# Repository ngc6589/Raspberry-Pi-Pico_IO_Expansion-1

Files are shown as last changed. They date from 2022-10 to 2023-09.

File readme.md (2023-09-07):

# Raspberry Pi Pico I/O Expansion Board

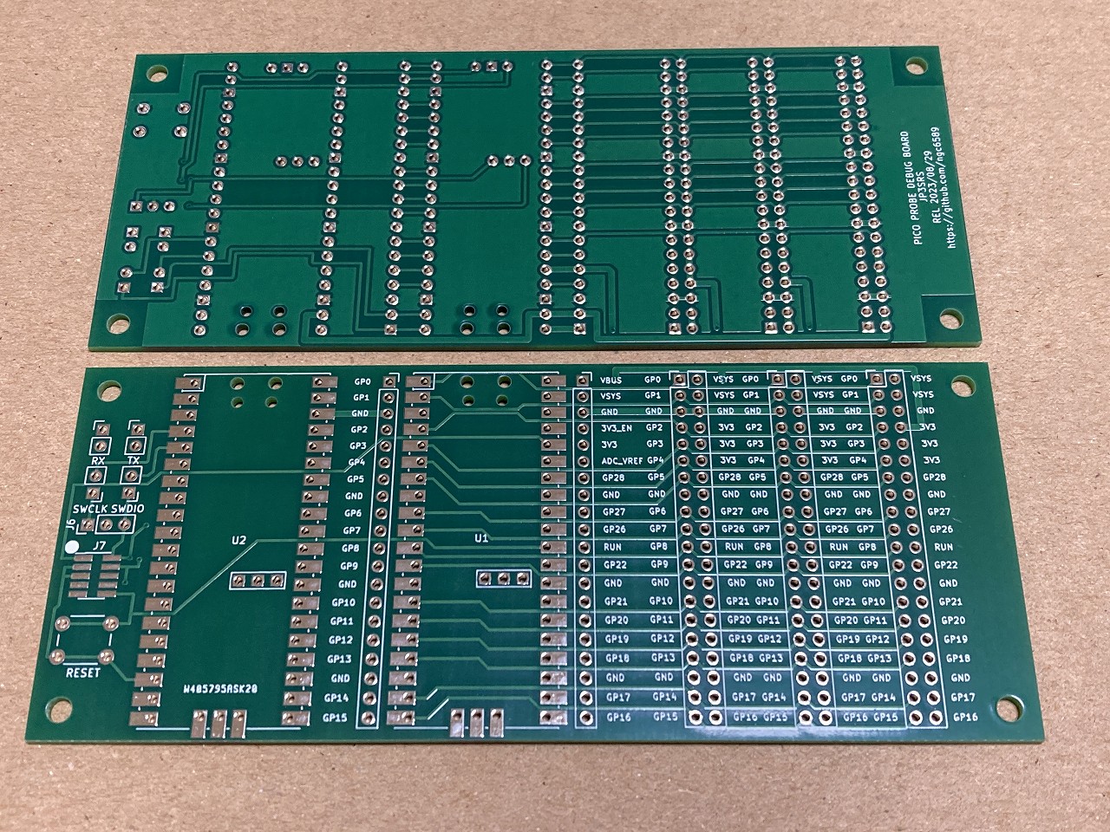
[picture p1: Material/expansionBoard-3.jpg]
expansionBoard


# この基板について

これは、Raspberry Pi Pico のピンを 2x20 のヘッダーピン（ピンソケット）に出す基板になります。ただし 2x20 ヘッダーピンは一部のピンを電源ピンに置き換えをしています。  
VBUS ピンは VSYS  
3V3_EN ピンは 3V3  
ADC_VREF は 3V3  

|Name|Pin|Pin|Name|
|---|---|---|---|
|GPIO0|1|40|VBUS → VSYS|
|GPIO1|2|39|VSYS|
|GND|3|38|GND|
|GPIO2|4|37|3V3_EN → 3V3|
|GPIO3|5|36|3V3|
|GPIO4|6|35|ADC_VREF → 3V3|
|GPIO5|7|34|GPIO28|
|GND|8|33|AGND|
|GPIO6|9|32|GPIO27|
|GPIO7|10|31|GPIO26|
|GPIO8|11|30|RUN|
|GPIO9|12|29|GPIO22|
|GND|13|28|GND|
|GPIO10|14|27|GPIO21|
|GPIO11|15|26|GPIO20|
|GPIO12|16|25|GPIO19|
|GPIO13|17|24|GPIO18|
|GND|18|23|GND|
|GPIO14|19|22|GPIO17|
|GPIO15|20|21|GPIO16|

# 回路図・ガーバーファイル
回路図は Schematic.pdf を参照してください。  
ガーバーファイルは KiCad フォルダーの Gerber-20230829 フォルダーを参照してください。

# Pico Probe 接続
基板端の U2 は Pico Probe の Raspberry Pi Pico が実装される場所です。gdb でデバッグをする時は実装してください。  
Pico Probe は使用しないけど、刺したまま使用するときは基板の JP1 ～ JP4 のジャンパーピンを抜くことで分離できます。

# 電源
Pico Probe 用 Raspberry Pi Pico とターゲット(動作用)の Raspberry Pi Pico の VSYS 端子は接続されています。なので USB ケーブルをどちらに挿しても（同時挿し含む）Raspberry Pi Pico 並びに、2x20 ヘッダピン・ヘッダソケットの VSYS ピンには電源が供給されます。  
VSYS は USB コネクタの VBUS からショットキーバリアダイオード通過後の端子になるため 5V よりかは若干低い電圧であることは理解下さい。  
  
3V3 はターゲット Raspberry Pi Pico の 3V3 端子から供給されます。Raspberry Pi Pico の基板に 3.3V DC/DC コンバーターが搭載されていますが、Raspberry Pi Pico Datasheet の記載には、3V3 のピンは 300mA 以下推奨とあります。

# 組み立て例
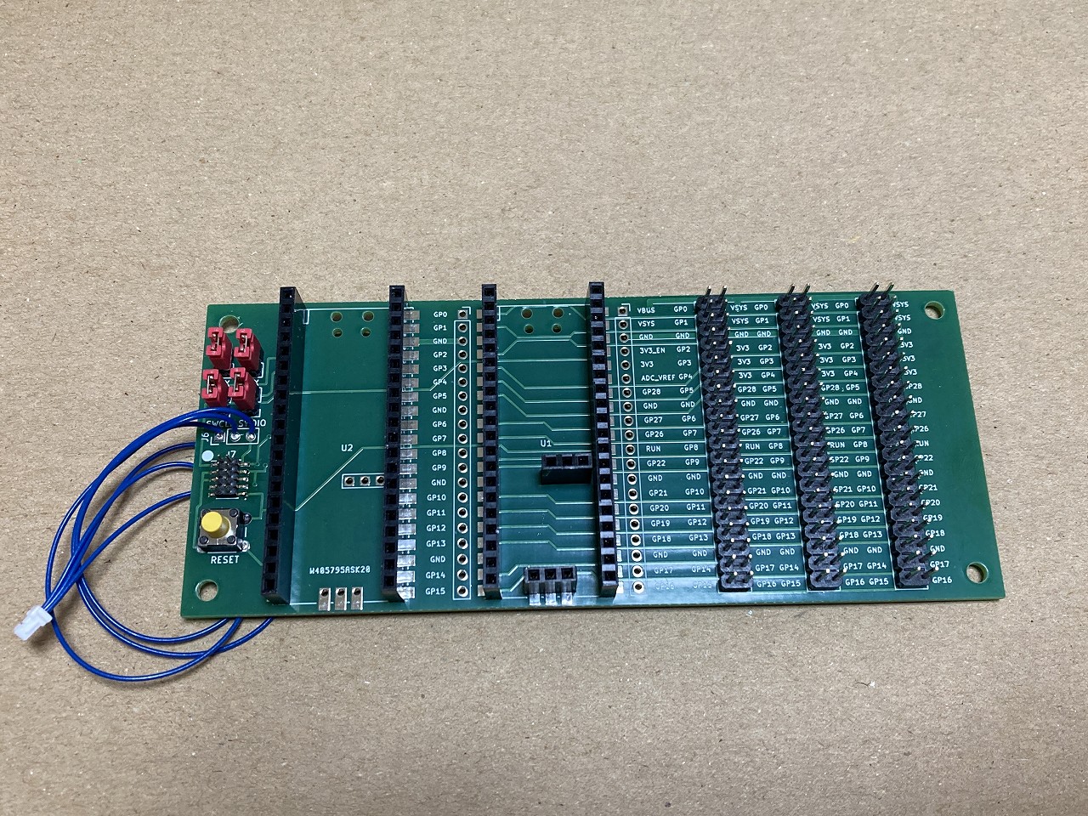
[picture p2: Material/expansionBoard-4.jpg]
expansionBoard


組み立て例は、Raspberry Pi Pico ボードをピンソケットで、横の I/O をピンヘッダーで出しました。
2x5 1.27mm ピッチヘッダピンは表面実装で、J-Link SWD 接続などで使うハーフピッチのコネクタ端子です。PicoProbe だけで使うときは実装不要です。

# 部品例

上記組み立て例の部品表は以下のようになります。

|部品番号|部品名|数量|通販アドレス|備考|
|---|---|---|---|---|
|U1, U2|ピンソケット (メス) 1×20 (20P)|4|https://akizukidenshi.com/catalog/g/gC-03077/||
|JP1～JP4|ピンヘッダ 1×2 (2P) (10個入)|1|https://akizukidenshi.com/catalog/g/gC-08593/||
|U1|ピンソケット(メス) 1×3(3P)|2|https://akizukidenshi.com/catalog/g/gC-10098/||
|J1, J2, J3|ピンヘッダ 2×20 (40P)|3|https://akizukidenshi.com/catalog/g/gC-00080/|
|JP1～JP4|ジャンパーピン赤(2.54mmピッチ) (25個入)|1|https://akizukidenshi.com/catalog/g/gP-03688/|
|SW1|タクトスイッチ（黄色）|1|https://akizukidenshi.com/catalog/g/gP-03650/|
|J6|コネクタ付コード 3P (青×3) 1mmピッチ|1|https://akizukidenshi.com/catalog/g/gC-11507/|
|J7|ピンヘッダ 2×5(10P) 表面実装用 1.27mmピッチ|1|https://akizukidenshi.com/catalog/g/gC-10904/|
|J4, J5|未実装||||

# 引用
Raspberry Pi PICO の KiCad ライブラリは https://github.com/ncarandini/KiCad-RP-Pico を利用しています。

# 使用例

## Raspberry Pi Pico
Raspberry Pi PIco は3ピンデバッグ端子にヘッダピンを付けて装着して下さい。
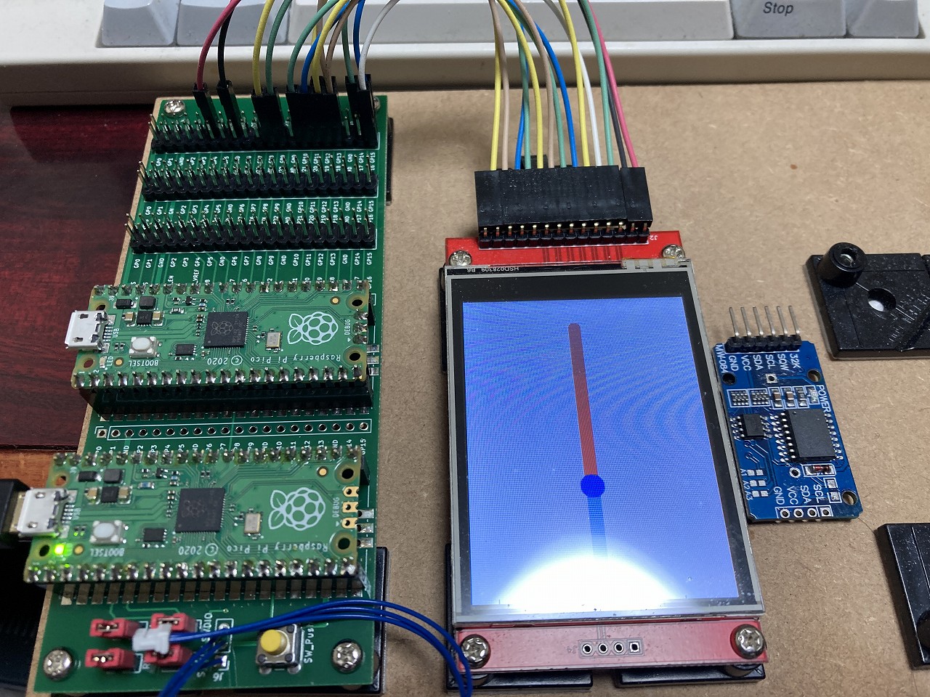
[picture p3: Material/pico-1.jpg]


## Raspberry Pi Pico H
ヘッダピンがあらかじめ実装されている Raspberry Pi Pico H はデバッグ端子は1mm間隔のJST SHコネクタになっています。基板からSHコネクタの線を出して接続します

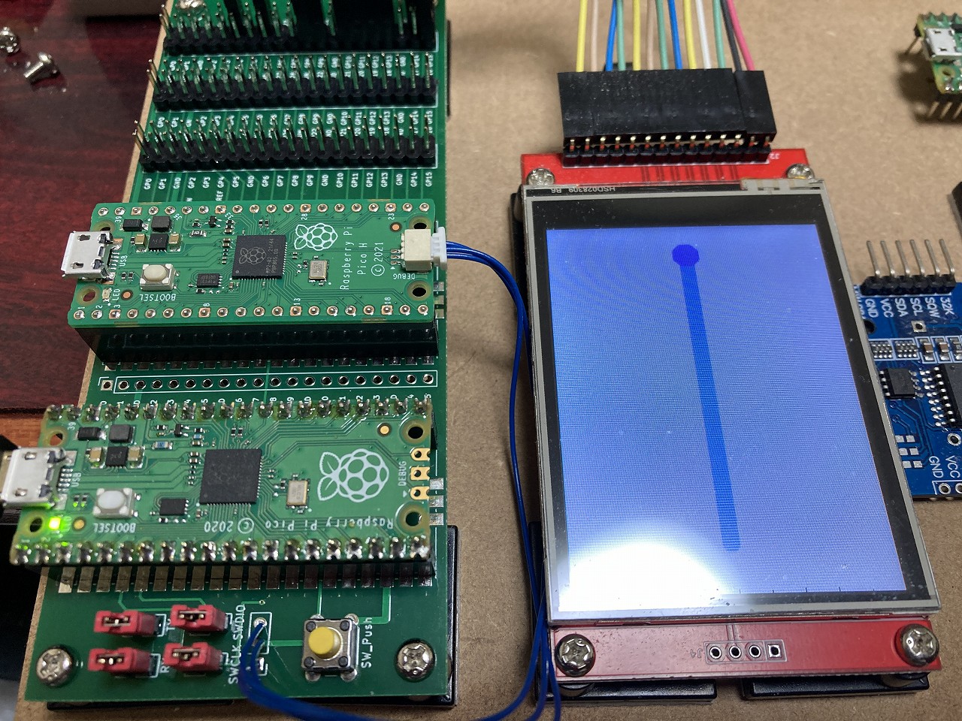
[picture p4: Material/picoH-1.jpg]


## Raspberry Pi Pico W
Raspberry Pi PIco 無線LAN付きは3ピンデバッグ端子にヘッダピンを付けて装着して下さい。

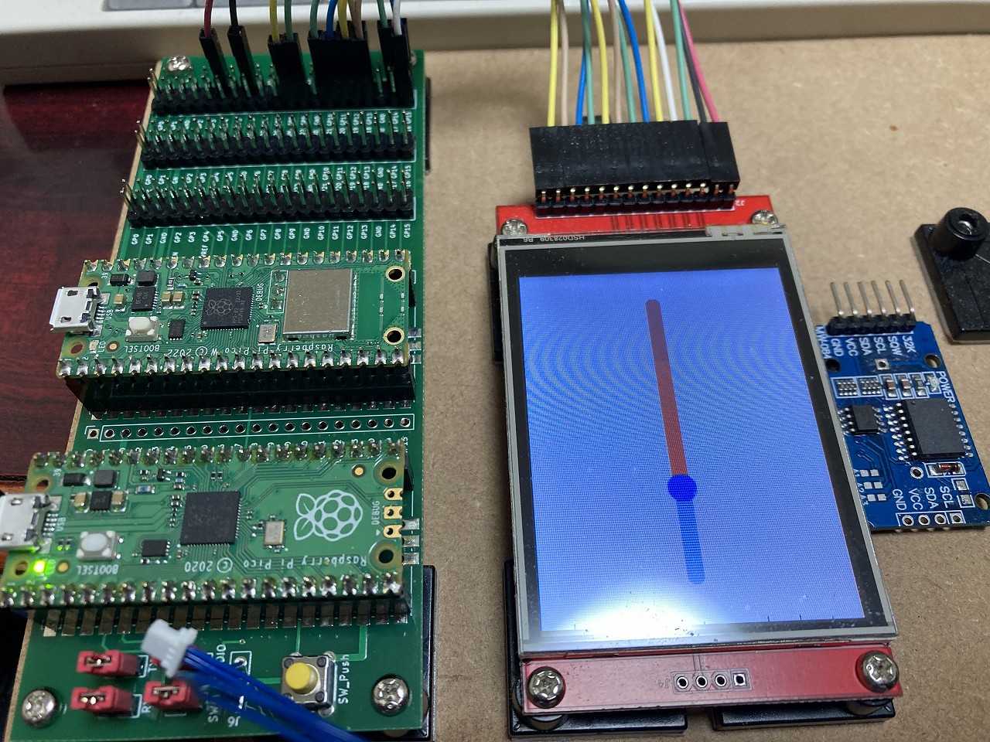
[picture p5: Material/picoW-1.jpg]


## Raspberry Pi Pico WH
ヘッダピン付き Raspberry Pi Pico HW は入手出来ていませんので写真はありませんが、Pico H 同様 JST SH コネクタでデバッグ端子に接続して下さい。

## SWD 接続のデバッガで使用する

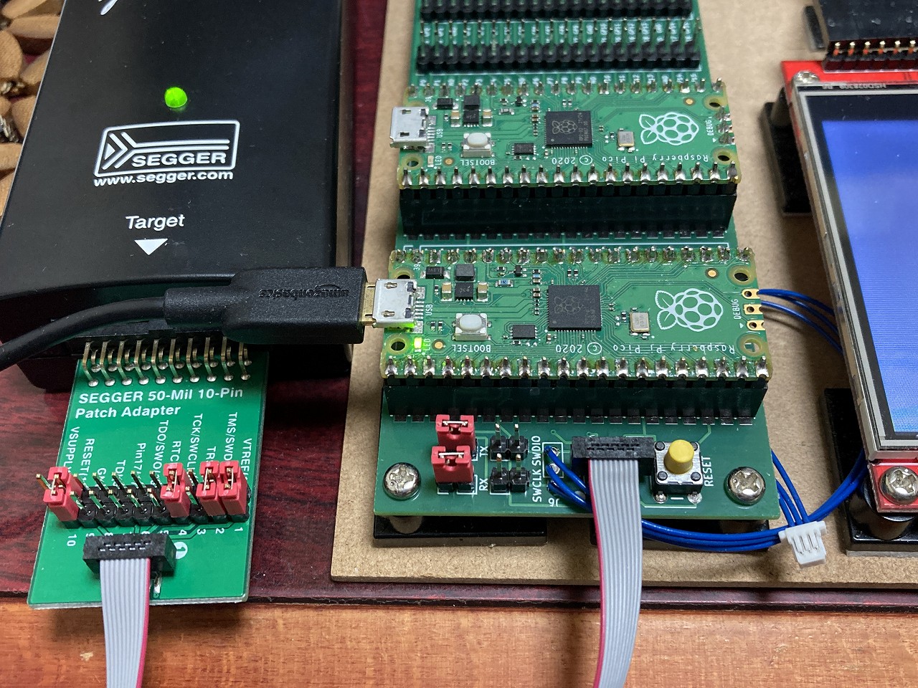
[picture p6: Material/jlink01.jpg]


2x5 ヘッダピンに SWD 接続可能なデバッガのケーブルを取り付けることで、違うデバッガを使用することができます。

**基板の SWD/SWCLK のジャンパは抜いてください。PicoProbe とショートしますので故障の原因となります。**

この接続でも PicoProbe は USB シリアルとして使用可能ですので、Raspberry Pi Pico の puts 出力などは PicoProbe 経由で受けられます。

# 頒布

https://www.em9system.com/?p=1047

にて在庫限りでピンソケット、ピンヘッダなど部品付きセットを頒布しています。

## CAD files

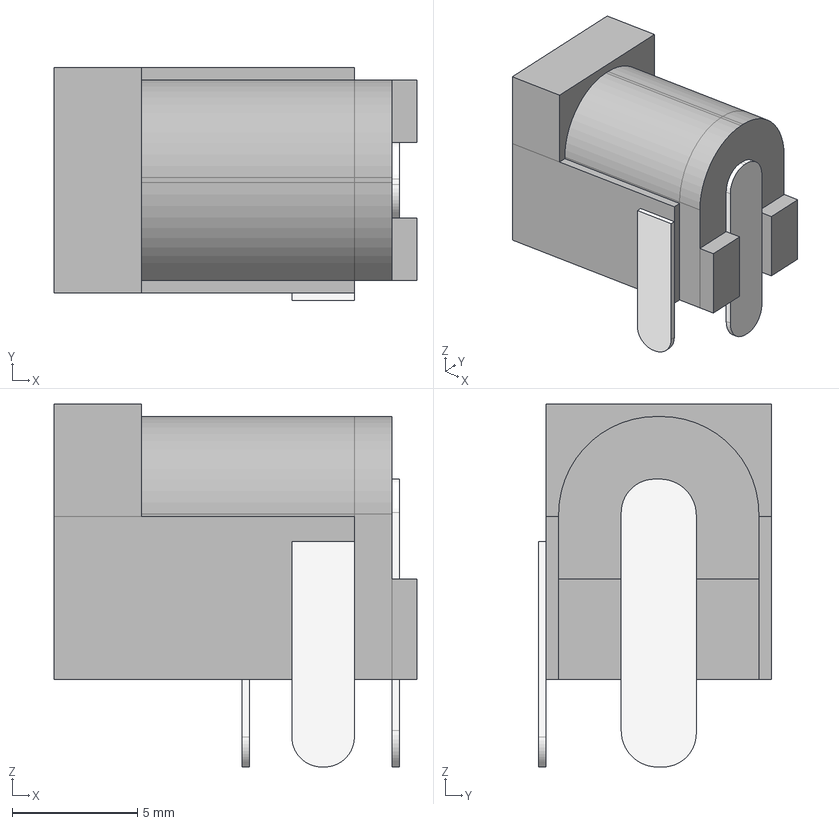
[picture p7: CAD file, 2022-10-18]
KiCad/_LocalLibraries/MJ-179PH-Part.step
14.5 x 9.30 x 14.5 mm

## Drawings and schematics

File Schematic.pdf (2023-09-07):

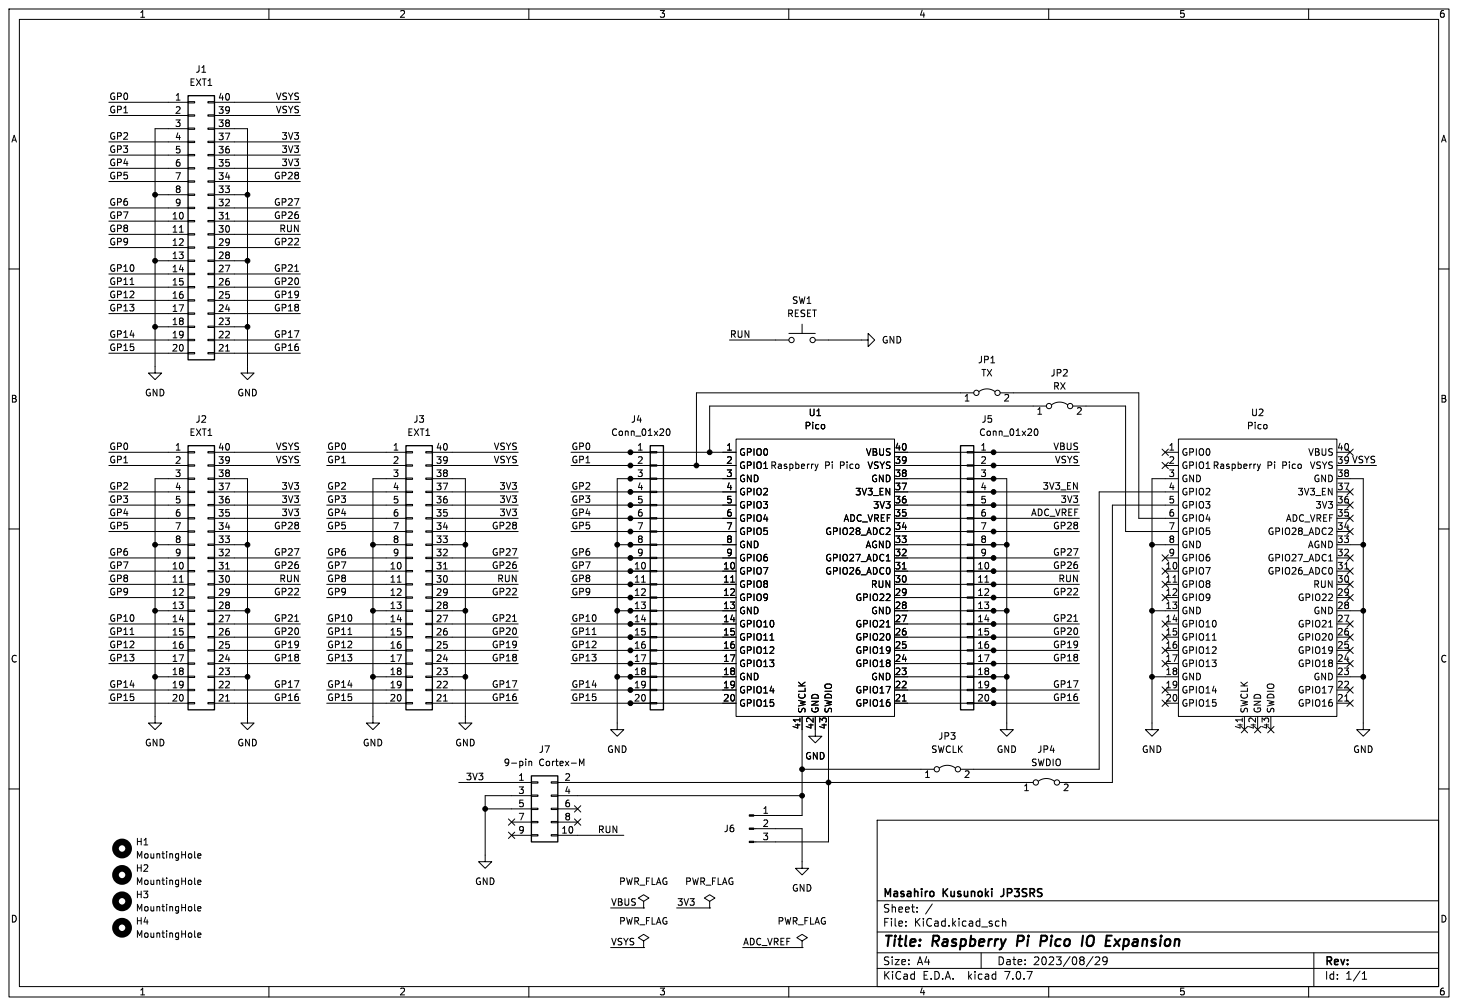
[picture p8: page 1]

Id: 1/1 Title: Raspberry Pi Pico IO Expansion

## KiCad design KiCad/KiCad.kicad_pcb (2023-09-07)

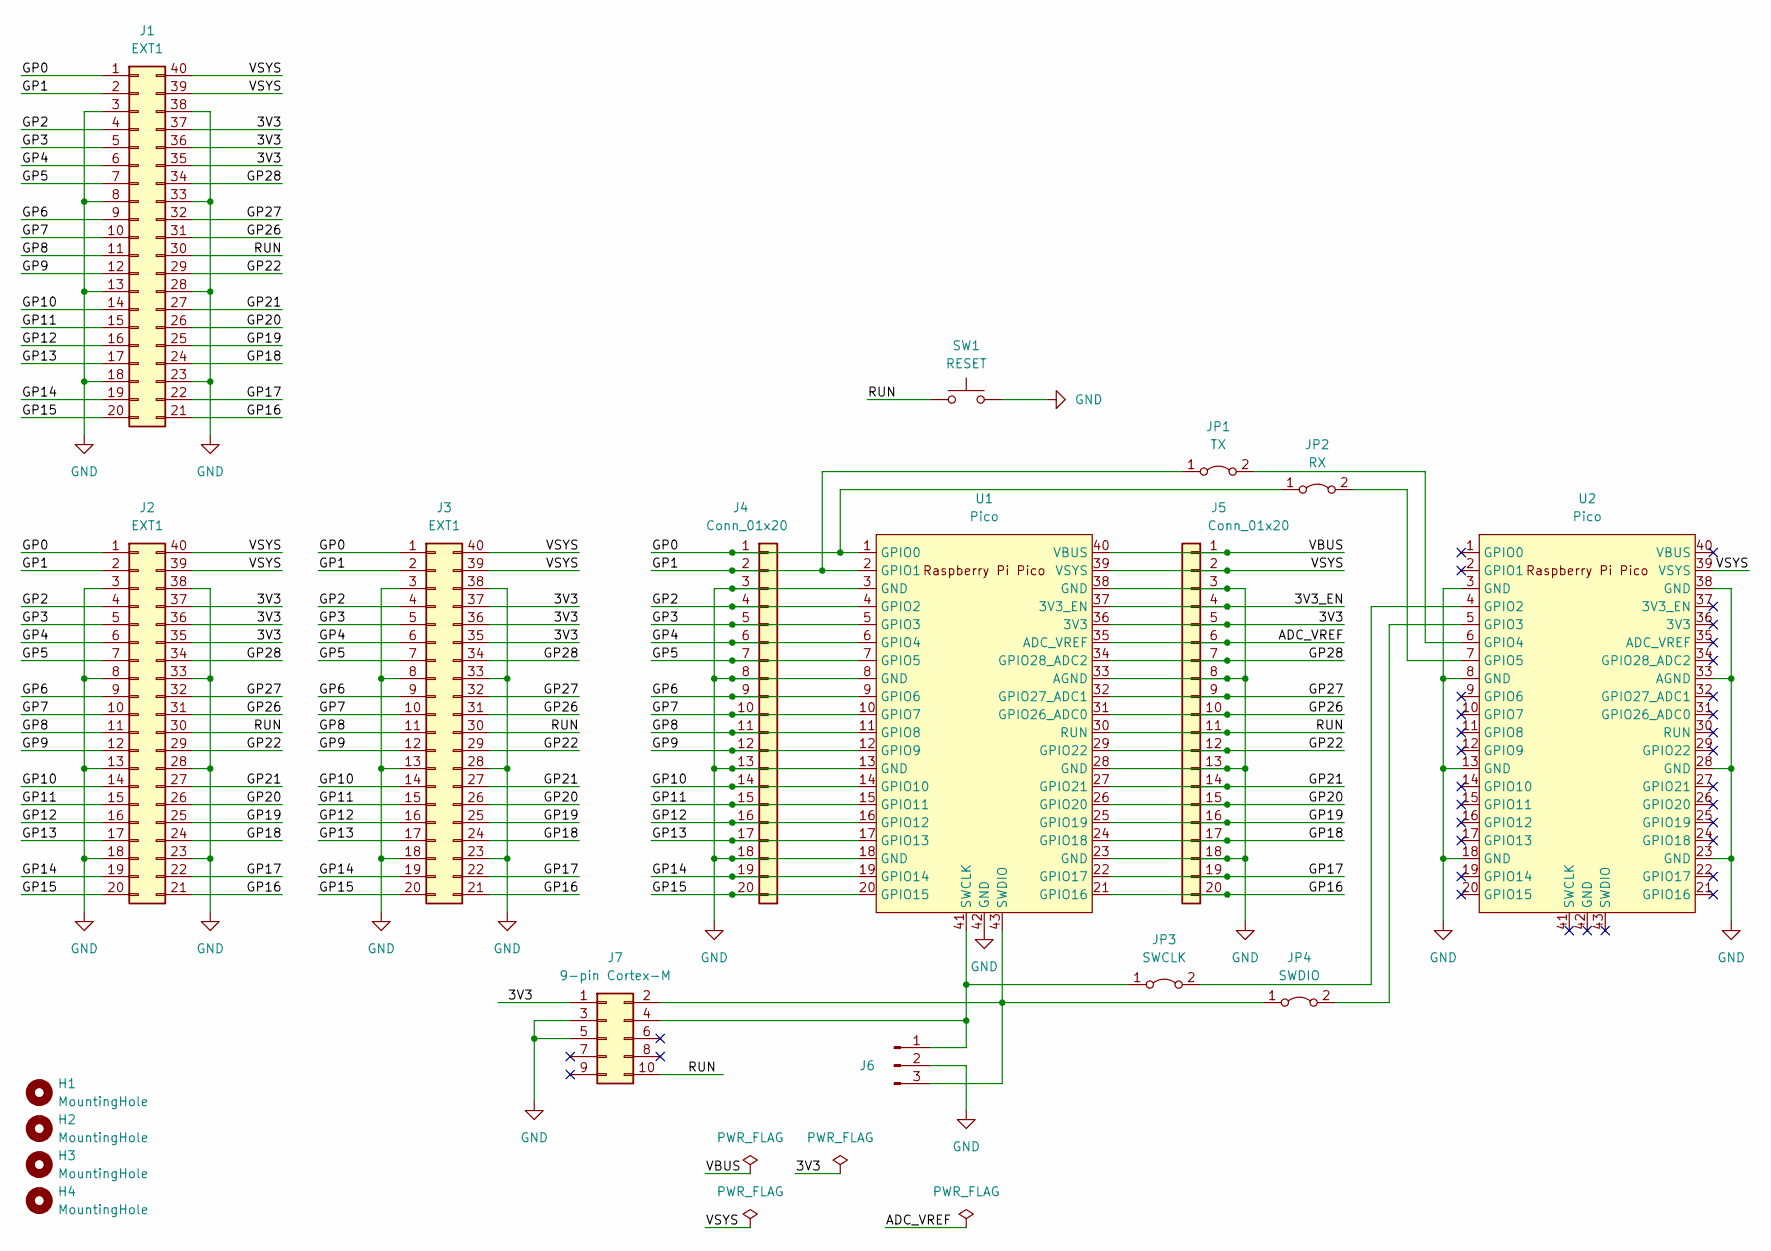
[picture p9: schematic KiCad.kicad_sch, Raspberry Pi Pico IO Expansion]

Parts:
H1, H2, H3, H4: MountingHole; MountingHole_3.2mm_M3
J1, J2, J3: EXT1; dualHeader
J4: Conn_01x20; leftHeader
J5: Conn_01x20; rightHeader
J6: Conn_01x03_Pin; PinHeader_1x03_P2.54mm_Vertical
J7: 9-pin Cortex-M; PinHeader_2x05_P1.27mm_Vertical_SMD
JP1: TX; PinHeader_1x02_P2.54mm_Vertical
JP2: RX; PinHeader_1x02_P2.54mm_Vertical
JP3: SWCLK; PinHeader_1x02_P2.54mm_Vertical
JP4: SWDIO; PinHeader_1x02_P2.54mm_Vertical
SW1: RESET; SW_PUSH_6mm
U1, U2: Pico; RPi_Pico_SMD_TH

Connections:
/3V3: J1.35, J1.36, J1.37, J2.35, J2.36, J2.37, J3.35, J3.36, J3.37, J5.5, J7.1, U1.36 (3V3)
/3V3_EN: J5.4, U1.37 (3V3_EN)
/ADC_VREF: J5.6, U1.35 (ADC_VREF)
/GP0: J1.1, J2.1, J3.1, J4.1, JP2.1 (A), U1.1 (GPIO0)
/GP1: J1.2, J2.2, J3.2, J4.2, JP1.1 (A), U1.2 (GPIO1)
/GP2: J1.4, J2.4, J3.4, J4.4, U1.4 (GPIO2)
/GP3: J1.5, J2.5, J3.5, J4.5, U1.5 (GPIO3)
/GP4: J1.6, J2.6, J3.6, J4.6, U1.6 (GPIO4)
/GP5: J1.7, J2.7, J3.7, J4.7, U1.7 (GPIO5)
/GP6: J1.9, J2.9, J3.9, J4.9, U1.9 (GPIO6)
/GP7: J1.10, J2.10, J3.10, J4.10, U1.10 (GPIO7)
/GP8: J1.11, J2.11, J3.11, J4.11, U1.11 (GPIO8)
/GP9: J1.12, J2.12, J3.12, J4.12, U1.12 (GPIO9)
/GP10: J1.14, J2.14, J3.14, J4.14, U1.14 (GPIO10)
/GP11: J1.15, J2.15, J3.15, J4.15, U1.15 (GPIO11)
/GP12: J1.16, J2.16, J3.16, J4.16, U1.16 (GPIO12)
/GP13: J1.17, J2.17, J3.17, J4.17, U1.17 (GPIO13)
/GP14: J1.19, J2.19, J3.19, J4.19, U1.19 (GPIO14)
/GP15: J1.20, J2.20, J3.20, J4.20, U1.20 (GPIO15)
/GP16: J1.21, J2.21, J3.21, J5.20, U1.21 (GPIO16)
/GP17: J1.22, J2.22, J3.22, J5.19, U1.22 (GPIO17)
/GP18: J1.24, J2.24, J3.24, J5.17, U1.24 (GPIO18)
/GP19: J1.25, J2.25, J3.25, J5.16, U1.25 (GPIO19)
/GP20: J1.26, J2.26, J3.26, J5.15, U1.26 (GPIO20)
/GP21: J1.27, J2.27, J3.27, J5.14, U1.27 (GPIO21)
/GP22: J1.29, J2.29, J3.29, J5.12, U1.29 (GPIO22)
/GP26: J1.31, J2.31, J3.31, J5.10, U1.31 (GPIO26_ADC0)
/GP27: J1.32, J2.32, J3.32, J5.9, U1.32 (GPIO27_ADC1)
/GP28: J1.34, J2.34, J3.34, J5.7, U1.34 (GPIO28_ADC2)
/RUN: J1.30, J2.30, J3.30, J5.11, J7.10, SW1.1, U1.30 (RUN)
/VBUS: J5.1, U1.40 (VBUS)
/VSYS: J1.39, J1.40, J2.39, J2.40, J3.39, J3.40, J5.2, U1.39 (VSYS), U2.39 (VSYS)
GND: J1.3, J1.8, J1.13, J1.18, J1.23, J1.28, J1.33, J1.38, J2.3, J2.8, J2.13, J2.18, J2.23, J2.28, J2.33, J2.38, J3.3, J3.8, J3.13, J3.18, J3.23, J3.28, J3.33, J3.38, J4.3, J4.8, J4.13, J4.18, J5.3, J5.8, J5.13, J5.18, J6.2, J7.3, J7.5, SW1.2, U1.3 (GND), U1.8 (GND), U1.13 (GND), U1.18 (GND), U1.23 (GND), U1.28 (GND), U1.33 (AGND), U1.38 (GND), U1.42 (GND), U2.3 (GND), U2.8 (GND), U2.13 (GND), U2.18 (GND), U2.23 (GND), U2.28 (GND), U2.33 (AGND), U2.38 (GND)
unnamed: J6.1, J7.4, JP3.1 (A), U1.41 (SWCLK)
unnamed: J6.3, J7.2, JP4.1 (A), U1.43 (SWDIO)
unnamed: JP1.2 (B), U2.6 (GPIO4)
unnamed: JP2.2 (B), U2.7 (GPIO5)
unnamed: JP3.2 (B), U2.4 (GPIO2)
unnamed: JP4.2 (B), U2.5 (GPIO3)

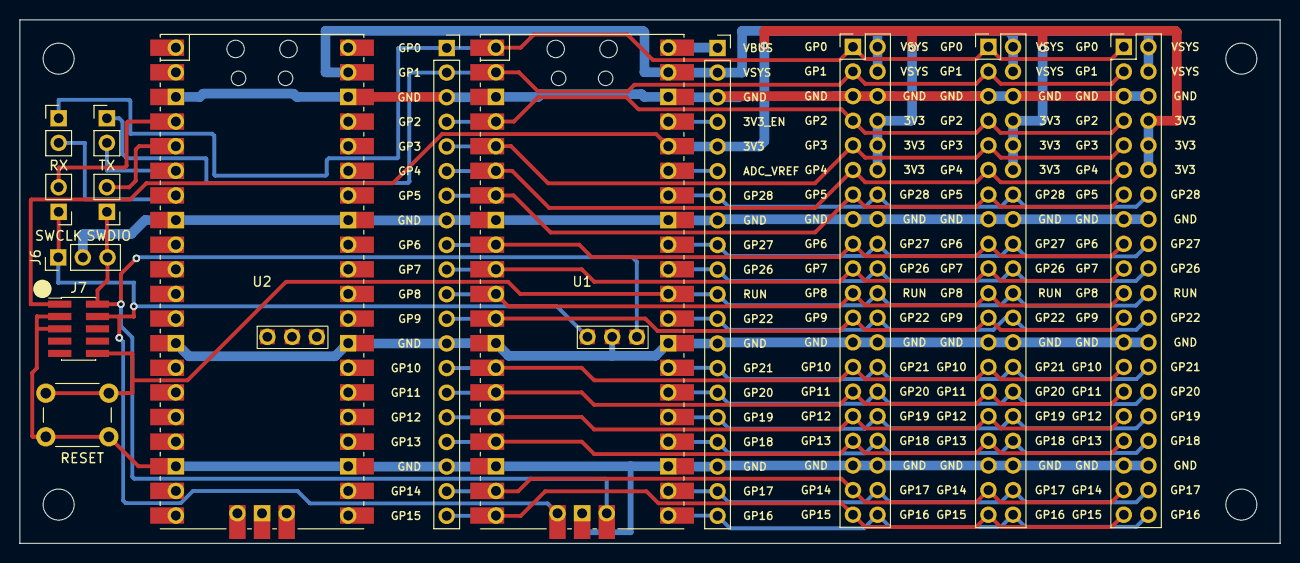
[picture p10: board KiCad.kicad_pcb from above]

Board: 2 copper layers, 130.0 x 54.0 mm, 18 parts (0 on the bottom side), 39 nets.

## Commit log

2023-06-03 update new PCB
    [KiCad-B_Cu.gbr, KiCad-B_Mask.gbr, KiCad-B_Paste.gbr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]
2023-09-07 update board revision
    [KiCad-B_Cu.gbr, KiCad-B_Mask.gbr, KiCad-B_Paste.gbr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]
2023-09-07 update material
